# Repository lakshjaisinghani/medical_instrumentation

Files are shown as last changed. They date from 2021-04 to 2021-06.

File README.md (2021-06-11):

# Aim
The aim of this project was to build an ECG amplifier using digital signal processing in software that works synergistically with readily available hardware components. Raw ECG signals are collected, processed, and displayed in real-time using an Arduino as a microcontroller and a python script as middleware. This report provides the design decisions, calculations and results obtained.

# Real-time Heart Rate plot output
<p align="center">
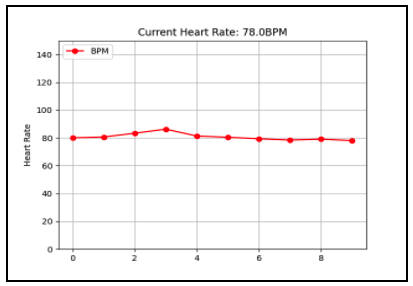
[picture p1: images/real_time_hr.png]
  
</p>

# Block Diagram
<p align="center">
  
</p>

# Components
| Component Type | Specification |
| --- | --- |
| Instrumentation Amplifier | INA114A |
| Op-Amp | LMC660 Quad Op-Amp |
| Resistors | 1x470kΩ, 3x2.2kΩ, 5x10kΩ, 1x100Ω |
| Capacitors  | 4x10μF |
| Batteries  | 2x9V |
| Microcontroller | Arduino Uno |
| ECG Electrodes  | 3 x 4mm banana to clip |
| Breadboard | 2 x mini-standard (83mmx55mm) |

# Final Circuit
## Bread board
<p align="center">
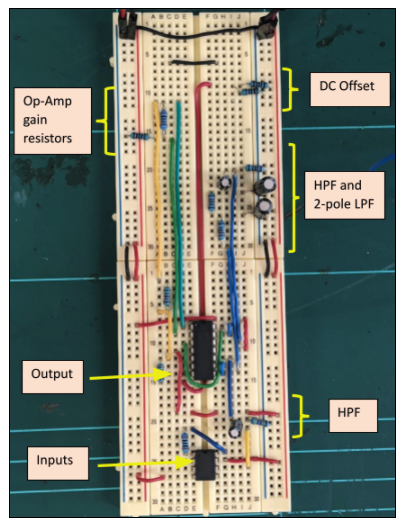
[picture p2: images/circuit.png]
  
</p>

## LTspice
<p align="center">
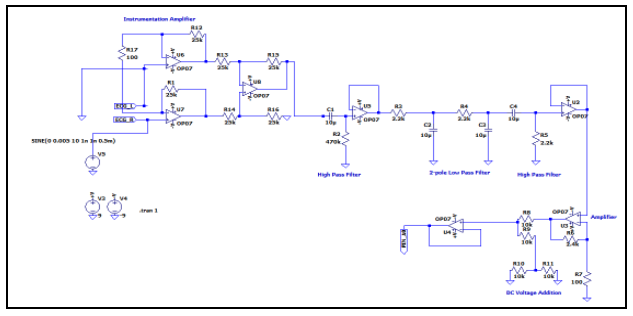
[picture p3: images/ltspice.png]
  
</p>

# Analog signal precessing results 
After each filtering stage:
<p align="center">
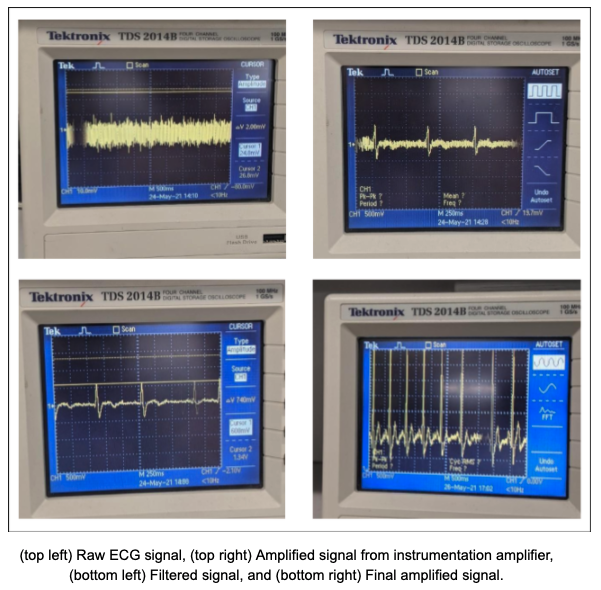
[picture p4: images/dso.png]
  
</p>

# Digital signal precessing results 
<p align="center">
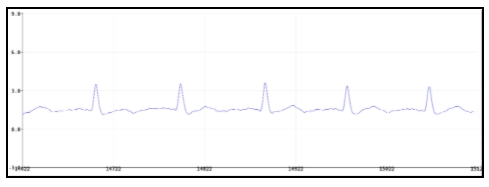
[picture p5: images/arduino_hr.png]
  
</p>

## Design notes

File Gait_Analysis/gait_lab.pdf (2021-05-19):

# ECE4081: Gait Lab

## Preliminary Questions

1. The two major calf muscles are the gastrocnemius (GA) and the soleus (SO).
2. The Gastrocnemius is responsible for plantar flexion at the ankle joint as it comprises half of the calf muscle and therefore is responsible for any fast-twitch movements (running, jumping, etc).

The soleus on the other hand, although responsible for plantar flexion at the ankle joint, mainly stabilizes the tibia limiting forward sway and hence is the most active when walking.

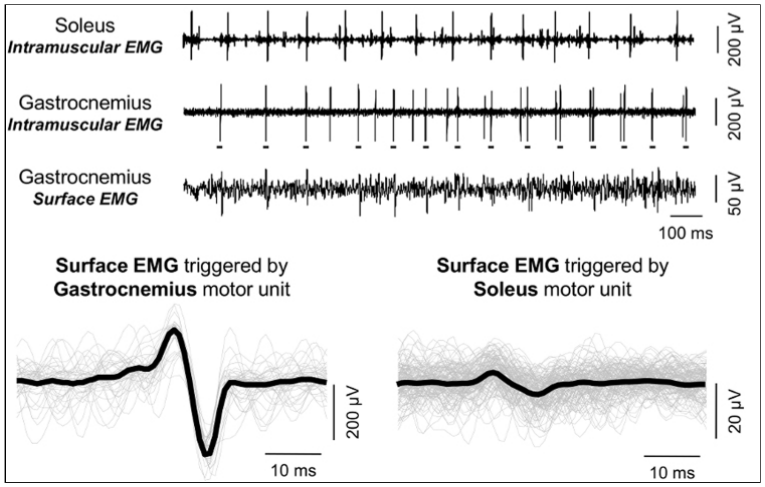
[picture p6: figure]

Fig 1. EMG from Soleus and Gastrocnemius. [1]

When looking at surface EMG data signals produced by the GA is almost 10x the magnitude of the Soleus, and intramuscularly, the SO produces more burst activity while the GA produces a single impulse [1].

3. We can place an accelerometer right above the hip, because:
a. As it is stiff, it minimizes the effects of the rotation of the body.
b. It also reduces height deviations while walking which could help us calculate the step length accurately.

4. The following is a diagram showing idiopathic toe walking, it’s a condition that involves abnormal gait due to toe strikes:

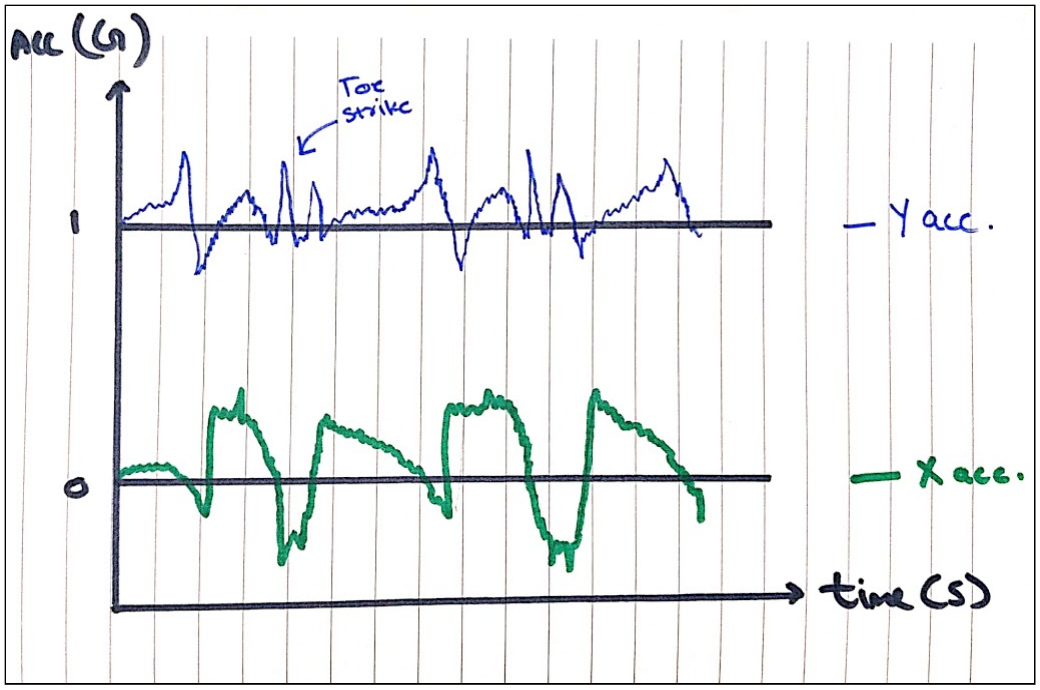
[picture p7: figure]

Fig 2. Idiopathic toe walking

## Analysing EMG Data

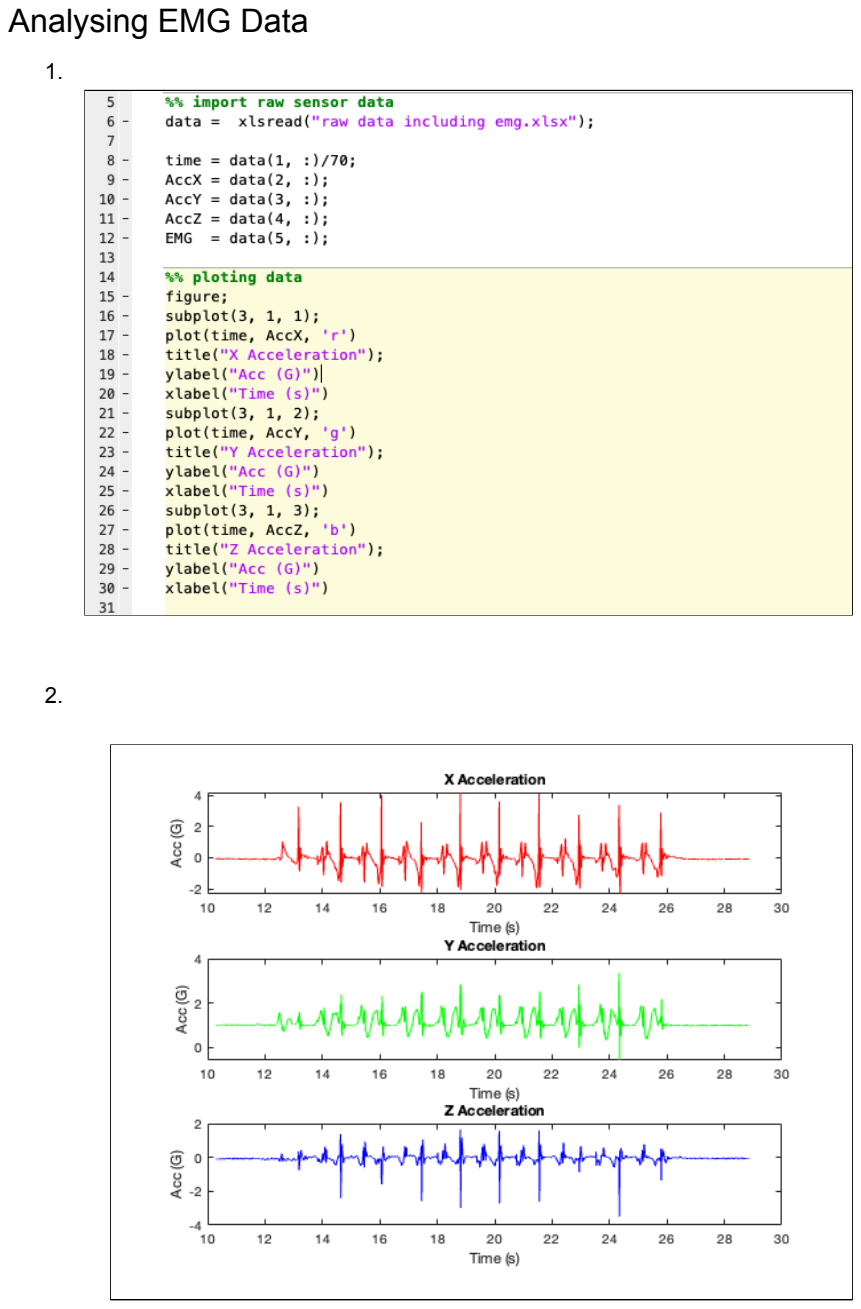
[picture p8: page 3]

1.

2.

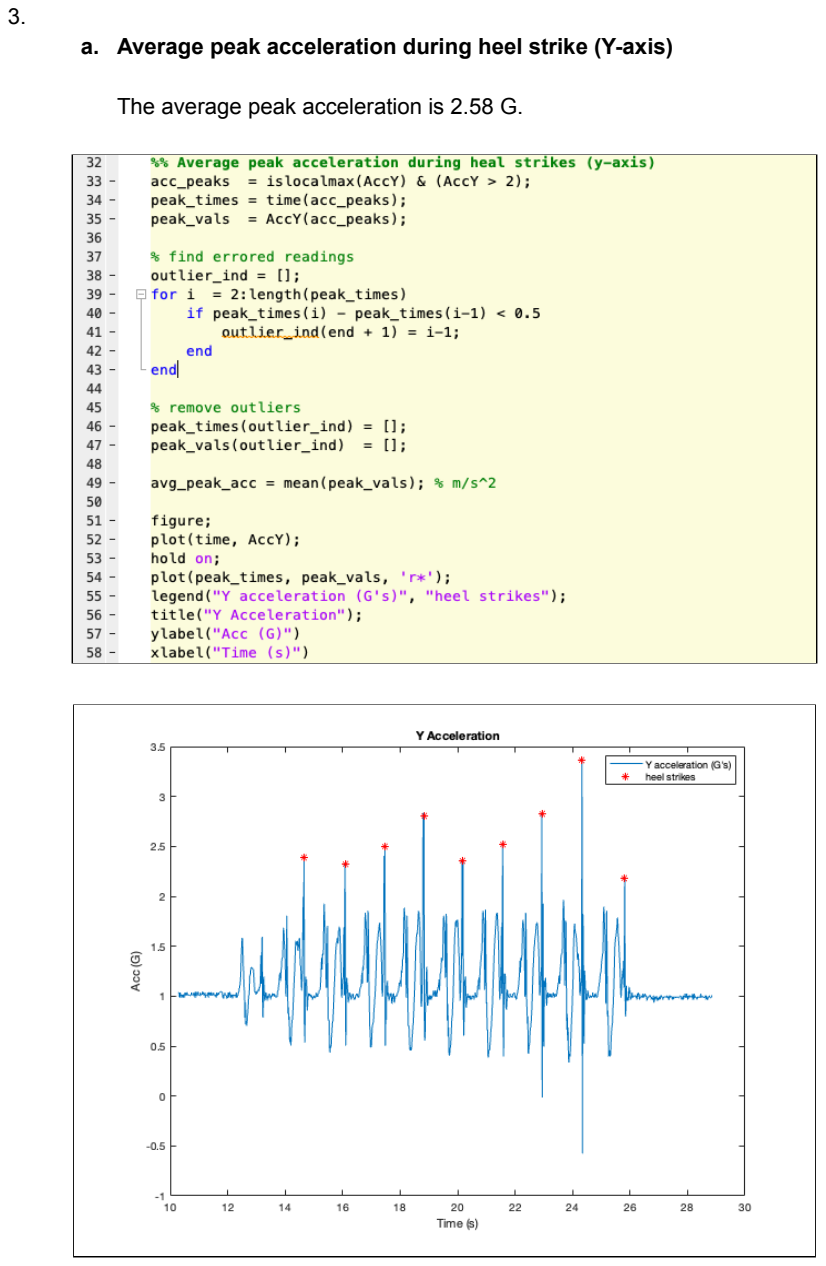
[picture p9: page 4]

3.
a. Average peak acceleration during heel strike (Y-axis)

The average peak acceleration is 2.58 G.

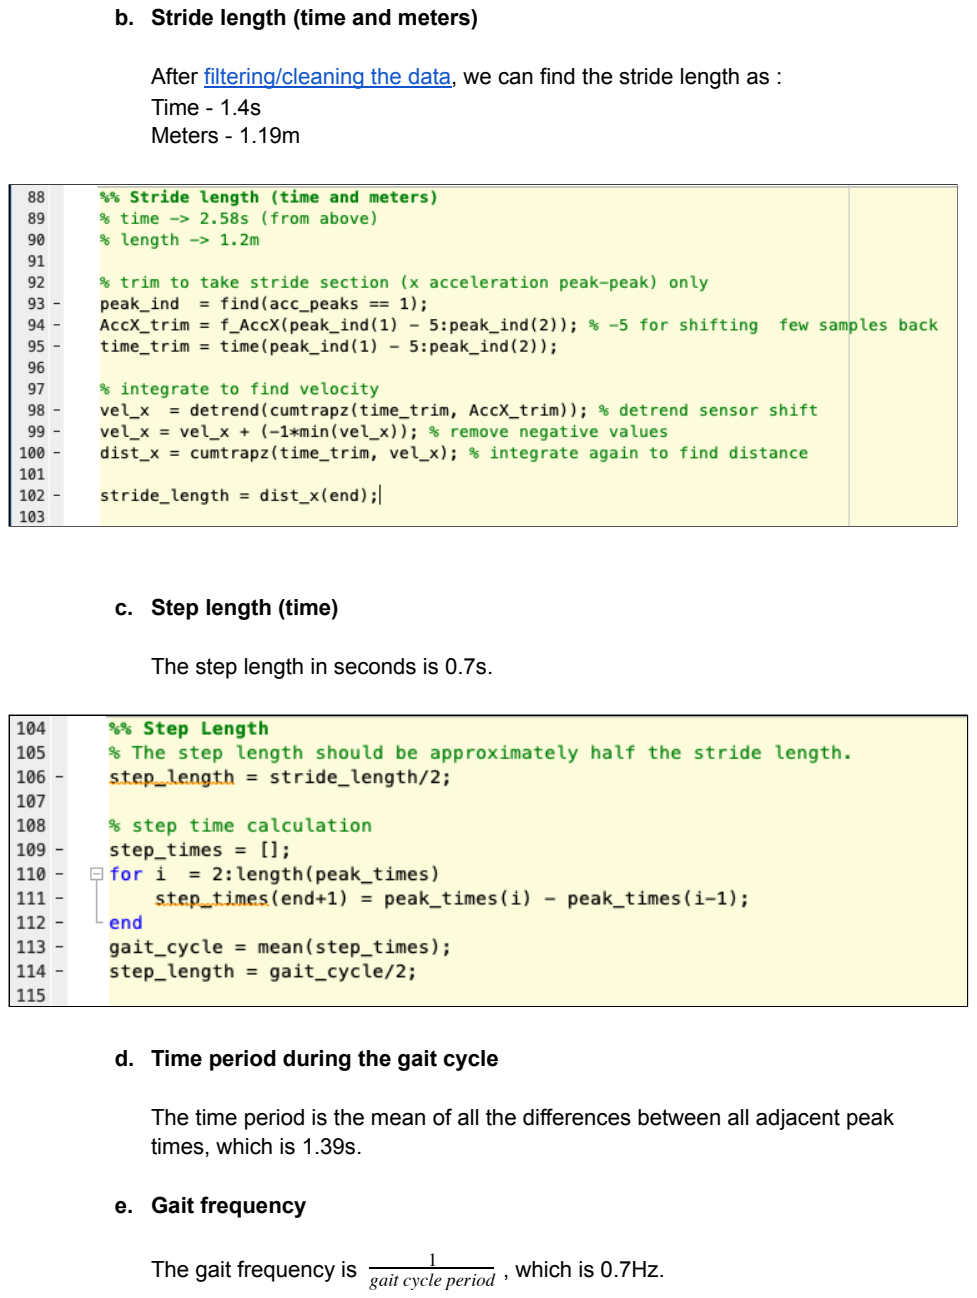
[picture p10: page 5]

b. Stride length (time and meters)

After filtering/cleaning the data, (https://github.com/lakshjaisinghani/medical_instrumentation/blob/master/Gait_Analysis/gait.m) we can find the stride length as : Time - 1.4s
Meters - 1.19m
c. Step length (time)

The step length in seconds is 0.7s.

d. Time period during the gait cycle

The time period is the mean of all the differences between all adjacent peak times, which is 1.39s.

e. Gait frequency
The gait frequency is | , which is 0.7Hz.

1
gait cycle period

## Discussion Questions

1. Surface EMG signals range from 20-200 μV [1]. Yes, amplification of the signal is required for ease of processing. Some muscles (like the biceps) may need less amplification compared to other muscles (like the muscles in our fingers) may require a higher gain [2].
2. The three sources of noise are:
a. High-Frequency Electromagnetic Radiation induced noise: This type of noise is inherent in all electronic devices, these are caused due to stray electromagnetic waves in the environment and power-line interference. We can remove such disturbances by filtering out high-frequency components (low pass filter) of the signal.
b. Low-Frequency patent artifacts: These include patient movement and other action potentials introduced into the measuring signal due to bodily functions. We can eliminate these by using a high pass filter.
c. Sensor noise: This noise is caused by the material property of the electrodes themselves, this includes Johnson–Nyquist noise (thermal noise), shot noise, and flicker noise. We can reduce such noise by using materials that produce a high signal-to-noise ratio like Ag/AgCl electrodes.

3.

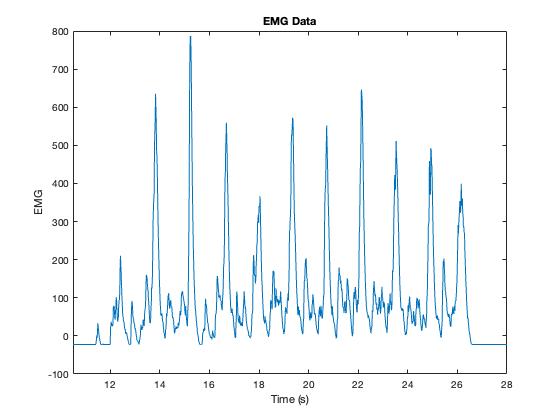
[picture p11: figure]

The EMG data provided is the calf EMG only. Therefore only two muscles, the gastrocnemius (GA) and the soleus (SO) EMG magnitude should be in the plot. These are the muscles involving forward motion.

Although not shown in the EMG, the Quadriceps femoris, the Rectus Femoris, the ILiopsoas, and the gluteus maximus are also responsible for forward motion.

4.

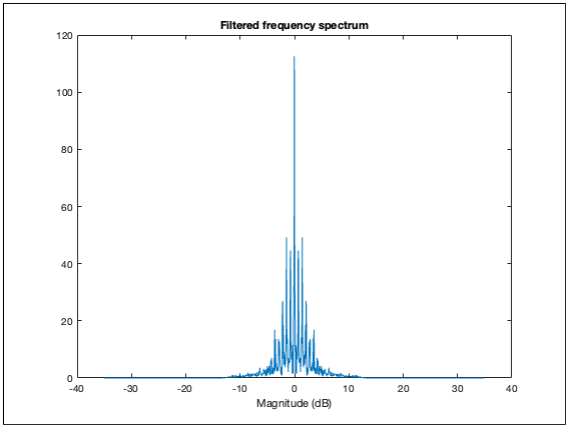
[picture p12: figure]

(Not considering the current sample frequency of 70 Hz) Looking at the frequency plot, the maximum frequency is around 10Hz, therefore we can sample from THIS SIGNAL at 20 samples/sec.

Else, we have to sample at double the Nyquist frequency, which is 140 samples/sec.

5. We can use a three-axis accelerometer in many medical health care monitoring conditions, but specifically, we can use them in fall detection and sleep monitoring.

Fall detection: We can use sudden accelerations to detect falls in either elderly or critical state patients (Parkinson’s, Alzheimer’s, etc).

Sleep monitoring: We can use movement data to measure the quality of sleep in patients. This can be a vital measurement in aiding chronic insomniacs.

6. Pressure sensors: Pressure sensors can allow medical staff to monitor the patient’s ground reactive force and calculate the weight distribution for stability study.

Accuracy: Using multiple cameras increases the accuracy of gait measurements in 3D space when compared to accelerometer-only measurements.

7. The average stride length in humans is about 0.762m. In general, | .42 | .3 Height
Step Length ≈ 0 | ± 0
[3].
8. We know that,
.42 | .3 Height
Step Length ≈ 0 | ± 0

Therefore,

0.42

1.57m

0.66 =

The Height of the individual is about 1.57m.

9. The three factors are:
a. Accuracy of the accelerometer.
b. Induced noise.
c. Sampling frequency.

Note: You can find the full code here. (https://github.com/lakshjaisinghani/medical_instrumentation/tree/master/Gait_Analysis)

## References

[1] T. Vieira, A. Botter, S. Miceli, and D. Farina, "Specificity of surface EMG recordings for gastrocnemius during upright standing", Scientific Reports, vol. 7, no. 1, 2017. Available: 10.1038/s41598-017-13369-1.
[2] M. Z. Jamal, "Signal Acquisition Using Surface EMG and Circuit Design Considerations for Robotic Prosthesis".
[3] S. Buddies, "Stepping Science: Estimating Someone's Height from Their Walk", Scientific American, 2021. [Online]. Available: https://www.scientificamerican.com/article/bring-science-home-estimating-height-walk/#:~:text=On%20av erage%2C%20adults%20have%20a,from%20about%200.41%20to%200.45). [Accessed: 16- Apr- 2021].

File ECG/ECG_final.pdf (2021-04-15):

# ECE4081: Lab 1

## Preliminary Questions

1.

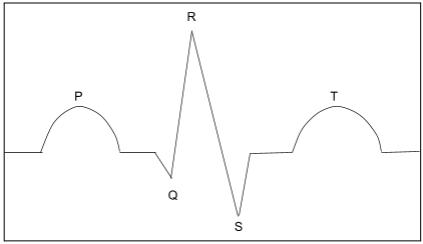
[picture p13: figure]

Fig 1: PQRST Wave

P wave - The first deflection is the P wave associated with right and left atrial depolarization. This causes atrial contraction [p-q section] (atrial fills with blood).

QRS complex - The QRS complex shows ventricular depolarisation. It is the electrical activity that first runs through the AV node, then through the interventricular septum, and finally through the ventricle walls.

T Wave - Shows ventricular repolarization. Before this, the s-t segment denotes ventricular contraction, i.e. blood flows out of ventricles.

2.

The three lead system is used to measure the differences between electrical potentials at different sites of the body on the frontal plane. The leads used are bipolar and are placed on the right arm, left arm and left leg (forming the einthoven's triangle).

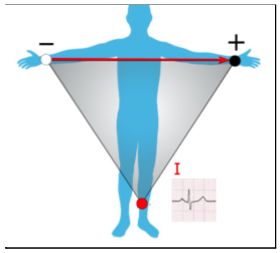
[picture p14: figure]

Fig 2. Einthoven's triangle [1]

It can be seen from the image below that each channel reads a slightly different PQRST complexes.That is, depending on the voltage read between two of the electrodes, the depolarisation and repolarisation electric vectors are seen from different views (some specific artifacts of the complex are more amplified from a certain view). Therefore looking at the same signal from different views gives us a better overall understanding of the complex.

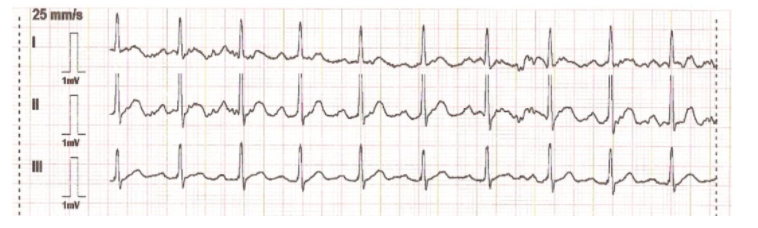
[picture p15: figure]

Fig 3. 3-Lead ECG from different reference points [2]

a) We use the direction of electrical flow across the cardiac tissue, referenced to the apex (Right to Left, lead 1) to get a clearer upright QRS complex (Specifically the P wave). This is because the direction of depolarization (electric vector) heads towards the positive electrode, which leads to the largest deviation in voltage magnitude [3, 4].
b) To view an electrical signal, we need to zero reference it to some known voltage to measure a potential difference.

3.

An RCD, or residual current device, is a life-saving device which is designed to prevent you from getting a fatal electric shock.

RCDs operate by measuring the current balance between two conductors using a differential current transformer. This measures the difference between current flowing through the live conductor and that returning through the neutral conductor.

Therefore, if there is a faulty medical device, which is not grounded correctly, that comes in contact with a lower resistance path to ground (victim of electrocution), it can trip the power supplied to the room which can reduce risks significantly.

## Data Collection and Recording

### ECG

### 1. Take a screenshot and identify the PQRST waveforms. What would happen if the

two electrode leads were swapped?

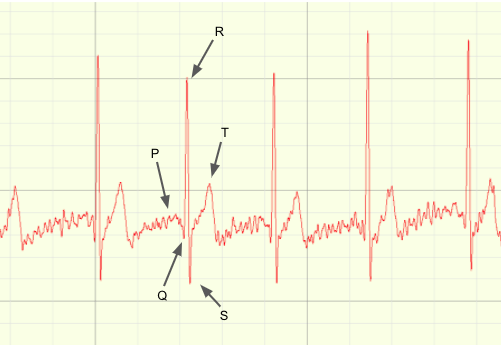
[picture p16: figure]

Fig 4. ECG sample

If the electrodes are swapped, the signal would be flipped, as shown in figure 5.

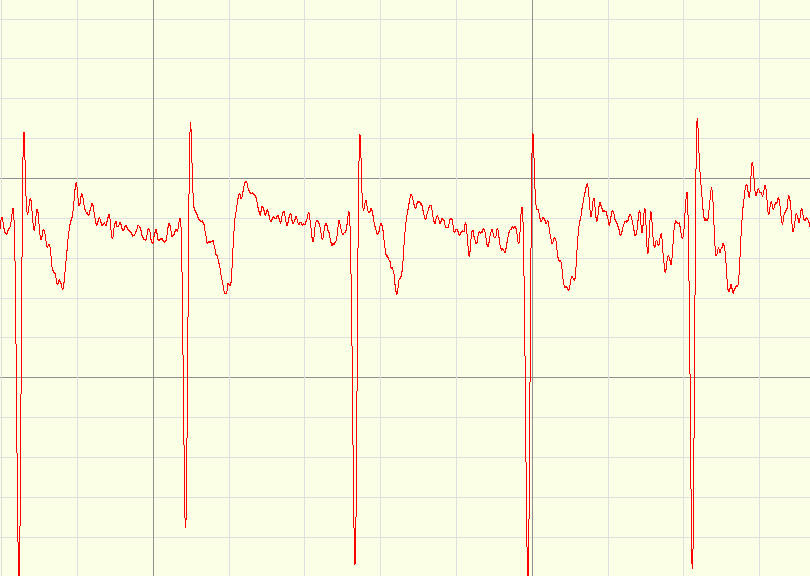
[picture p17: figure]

Fig 5. Flipped ECG signal sample

### 2. Turn off the 35-Hz LPN filter and take another recording. Observe what happens to

the signal. Explain why.

Turning off the 35-Hz low pass filter allows all the 50-Hz noise generated by the power source to appear at the signal. In the case of this lab we used an isolation transformer as the pseudo power source.

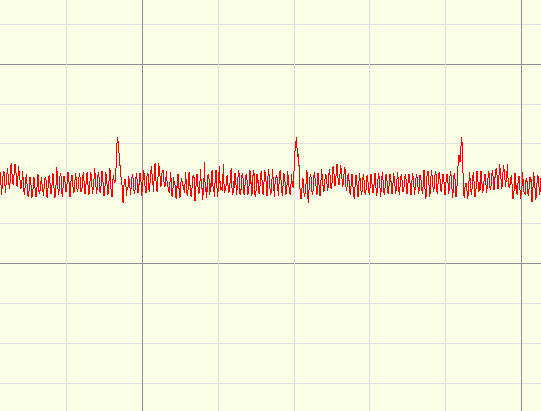
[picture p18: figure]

Fig 6. 35-Hz LPF turned off

### 3. Turn the 35-Hz LPN filter back on. Now turn off the HP filter and take another

recording. Observe what happens to the signal. Why?

The HP filter removes the slow oscillation frequencies introduced into the signal due to respiration. So, Turning it off introduces a low frequency component that causes the whole ECG signal to slow oscillations.

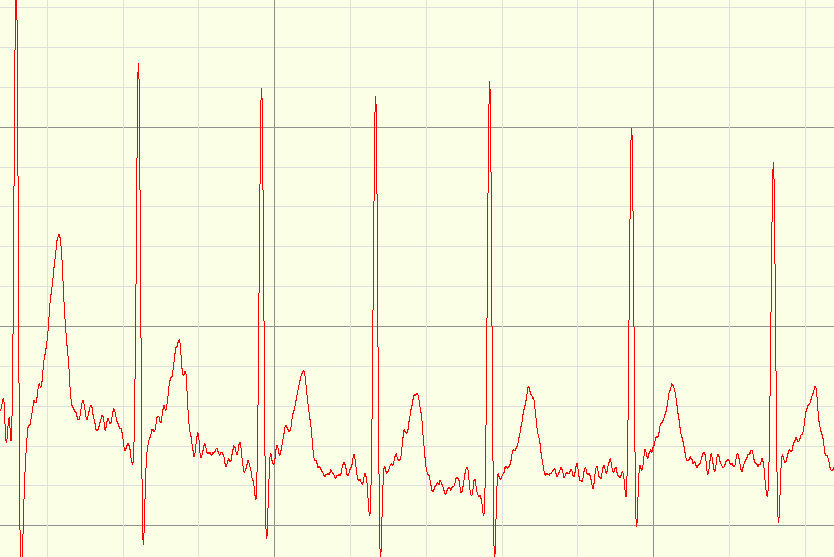
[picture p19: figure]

Fig 7. HP filter turned off

### 4. Disconnect the shield to one of the shielded electrodes. What happens?

Disconnecting the shield on one of the electrodes introduces the surrounding electromagnetic interference into the ECG signal.

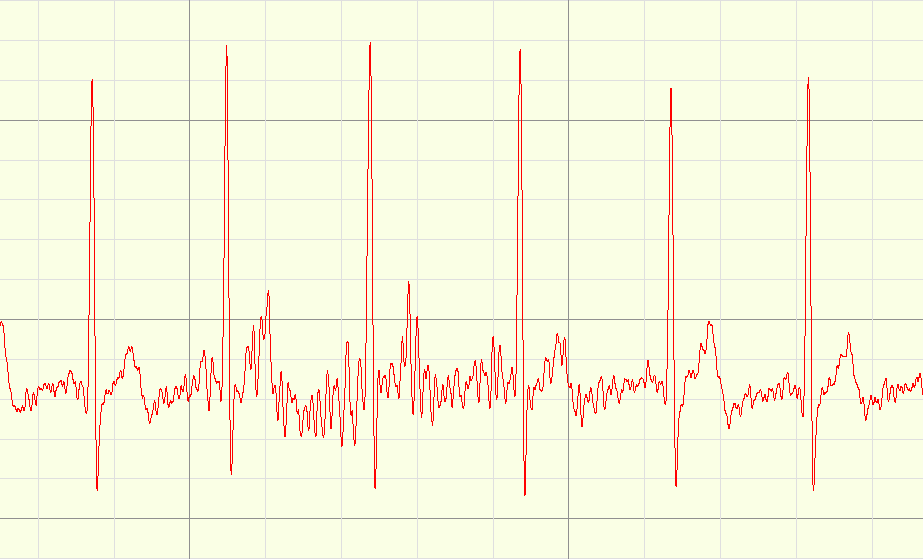
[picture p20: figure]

Fig 8. One shield disconnected

### 5. Disconnect the shield to the other electrode so that both shields are now

disconnected. What happens?

Disconnecting both shields ignores most of the EM interference. Probably due to the differential instrumentation amplifier in the monitors circuitry that rejects the common EM disturbance.

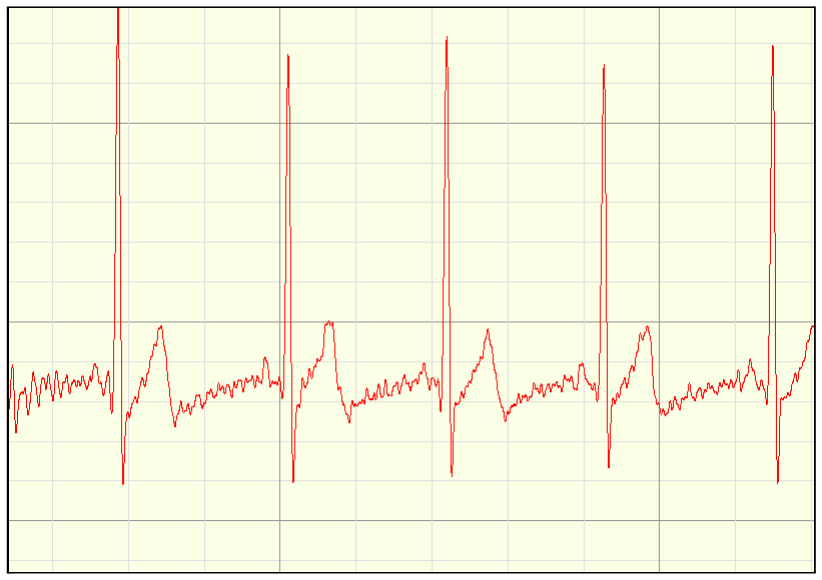
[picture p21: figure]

Fig 9. Both shields disconnected

### 6. Remove the gel from the electrode surfaces and take another recording. What

happens?

Removing the gel from the electrode surfaces didn’t cause much change when stationary. But, slight movements caused erroneous readings due to the conducting path between the skin and electrode not being consistent.

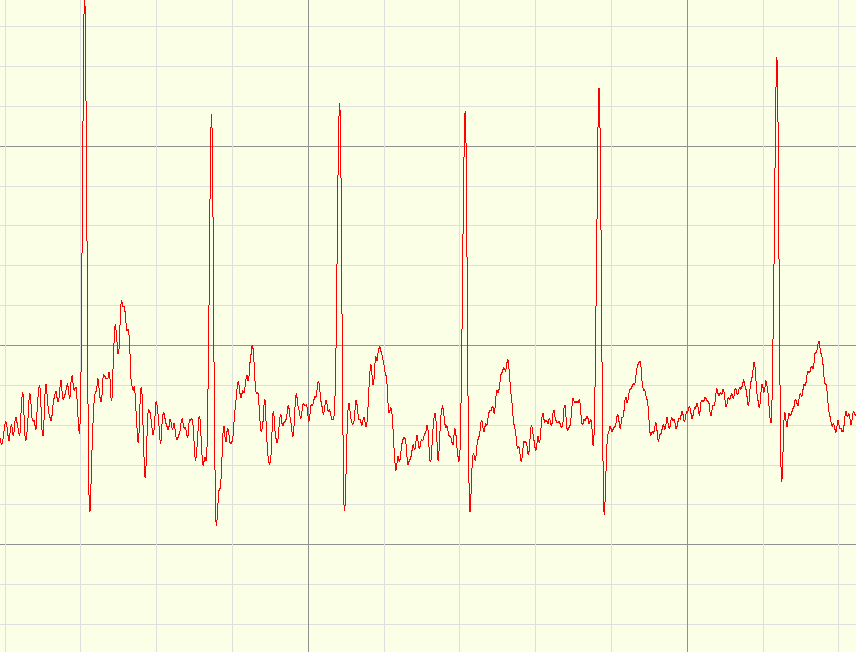
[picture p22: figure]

Fig 10. Removed gel from electrode surface

### 7. Use the Data Acquisition button to collect both ECG and R-R interval data for a 5

minute time interval. Is this what you would expect to see and why?

The R-R interval is the time difference between two R peaks in an ECG PQRST complex. The reading provided is what we expected, this is because it was constant for the most part, but as the heart rate increased the R-R interval decreased and vice-versa.

### SpO2

### 1. Observe the SpO2 waveform. How does it compare to the ECG waveform? What

are the differences? Why is it different?

The SpO2 waveform measures the concentration of oxygen under the tissue being measured. This concentration of oxygen is related to the amount of hemoglobin in the blood (oxygenated blood) being pumped by the heart to that tissue. Therefore, this signal has nothing to do with the electric vectors measured during an ECG.

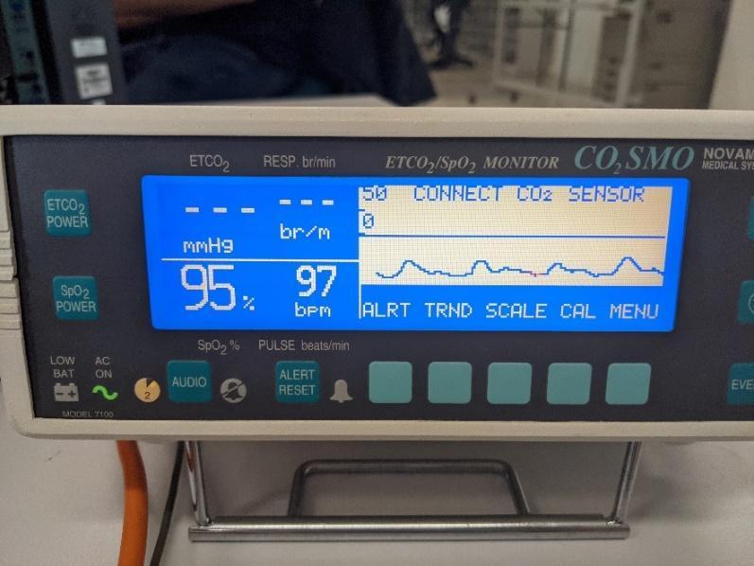
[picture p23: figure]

Fig 11. SpO2 waveform.

This distinction makes it clear that there would be no PQRST complex in an SpO2 waveform, but just the amount of oxygen over time. Hence, the signal is a lot smoother and has distinct peaks.

### 2. Manually calculate the interval between the peaks of SpO2 waveform. What can

you do to make this measurement more accurate?

In figure 3, there are almost 4 peaks in the 3 second interval. Therefore, there are 1.33 peaks per second. Which calculates to about 80 bpm.

## Discussion Questions

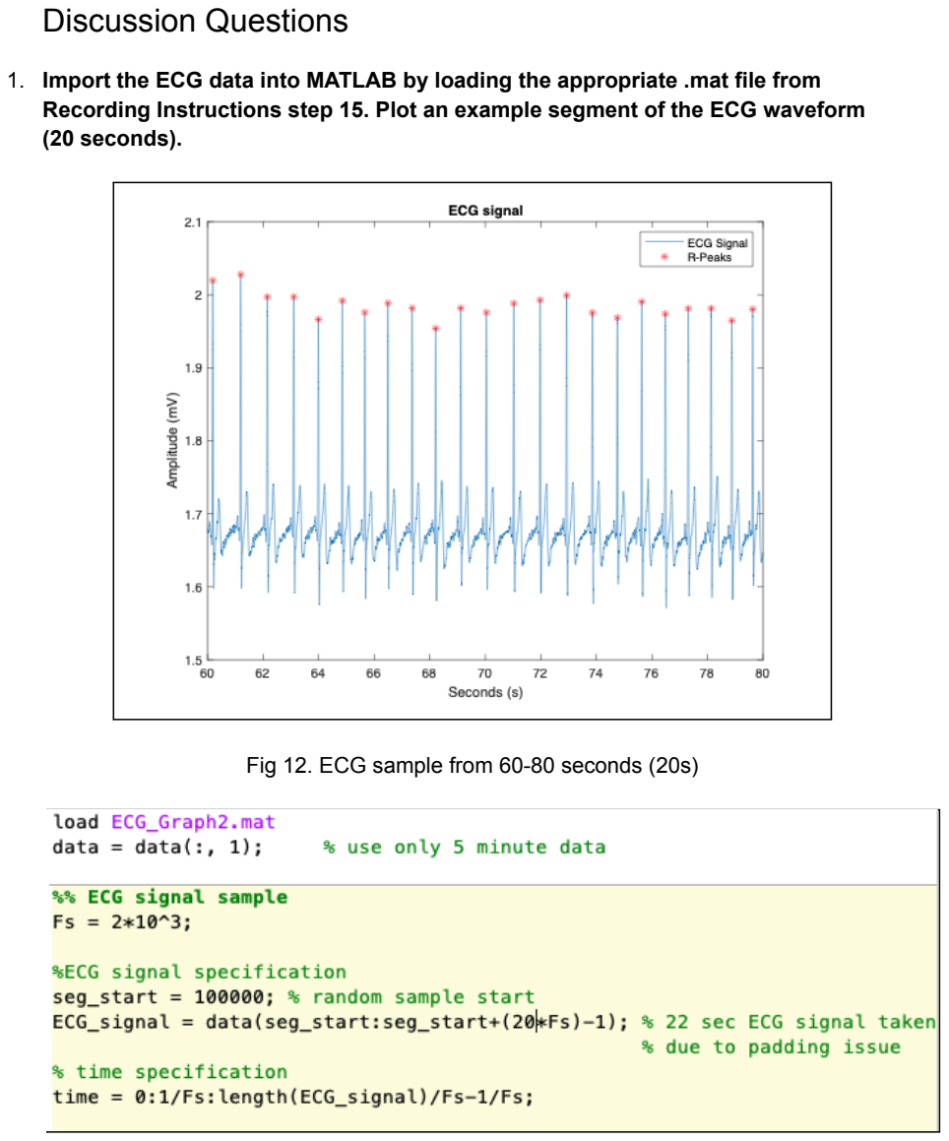
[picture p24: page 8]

1. Import the ECG data into MATLAB by loading the appropriate .mat file from Recording Instructions step 15. Plot an example segment of the ECG waveform (20 seconds).

Fig 12. ECG sample from 60-80 seconds (20s)

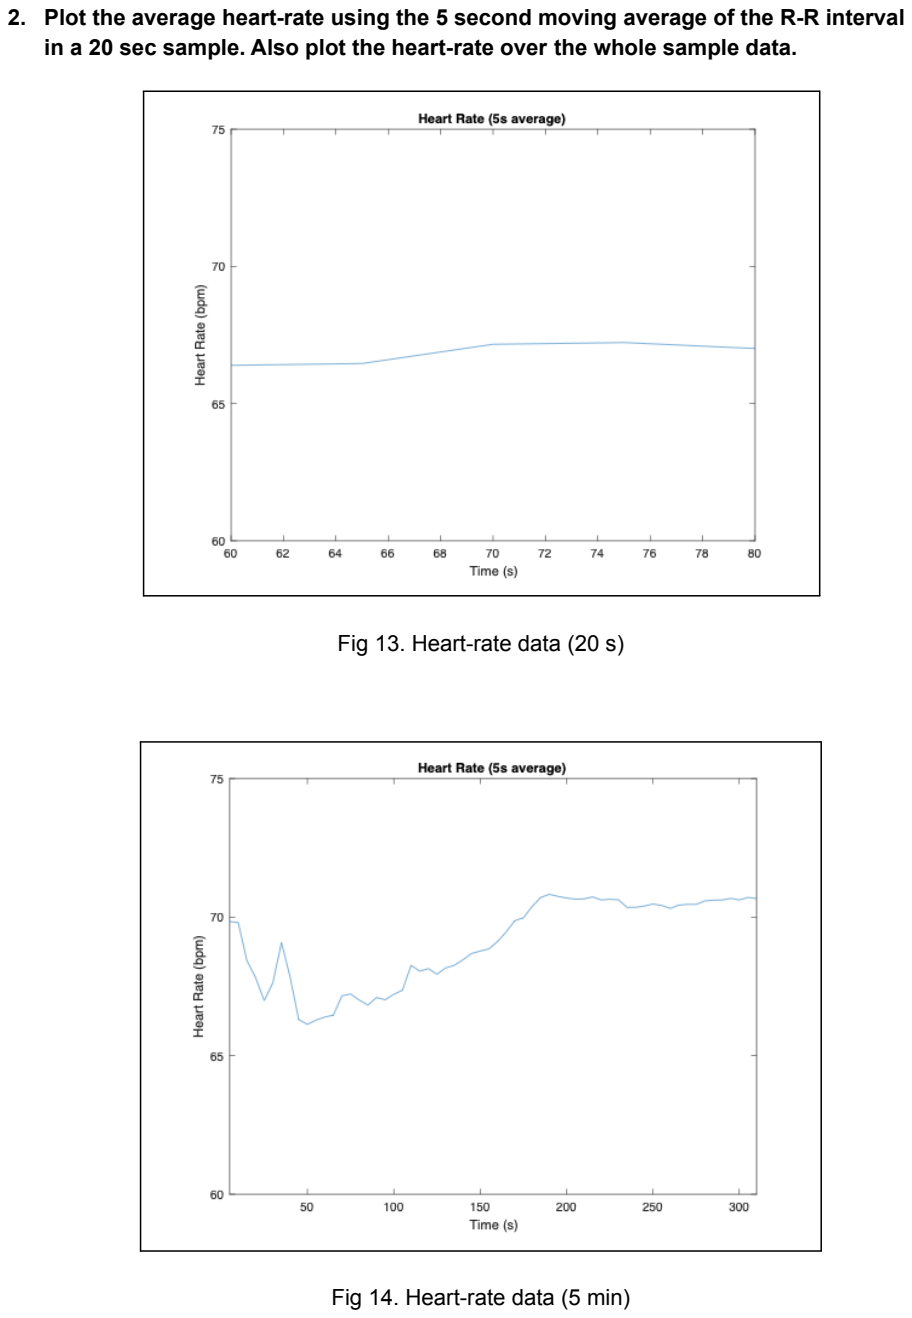
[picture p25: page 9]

### 2. Plot the average heart-rate using the 5 second moving average of the R-R interval

in a 20 sec sample. Also plot the heart-rate over the whole sample data.

Fig 13. Heart-rate data (20 s)

Fig 14. Heart-rate data (5 min)

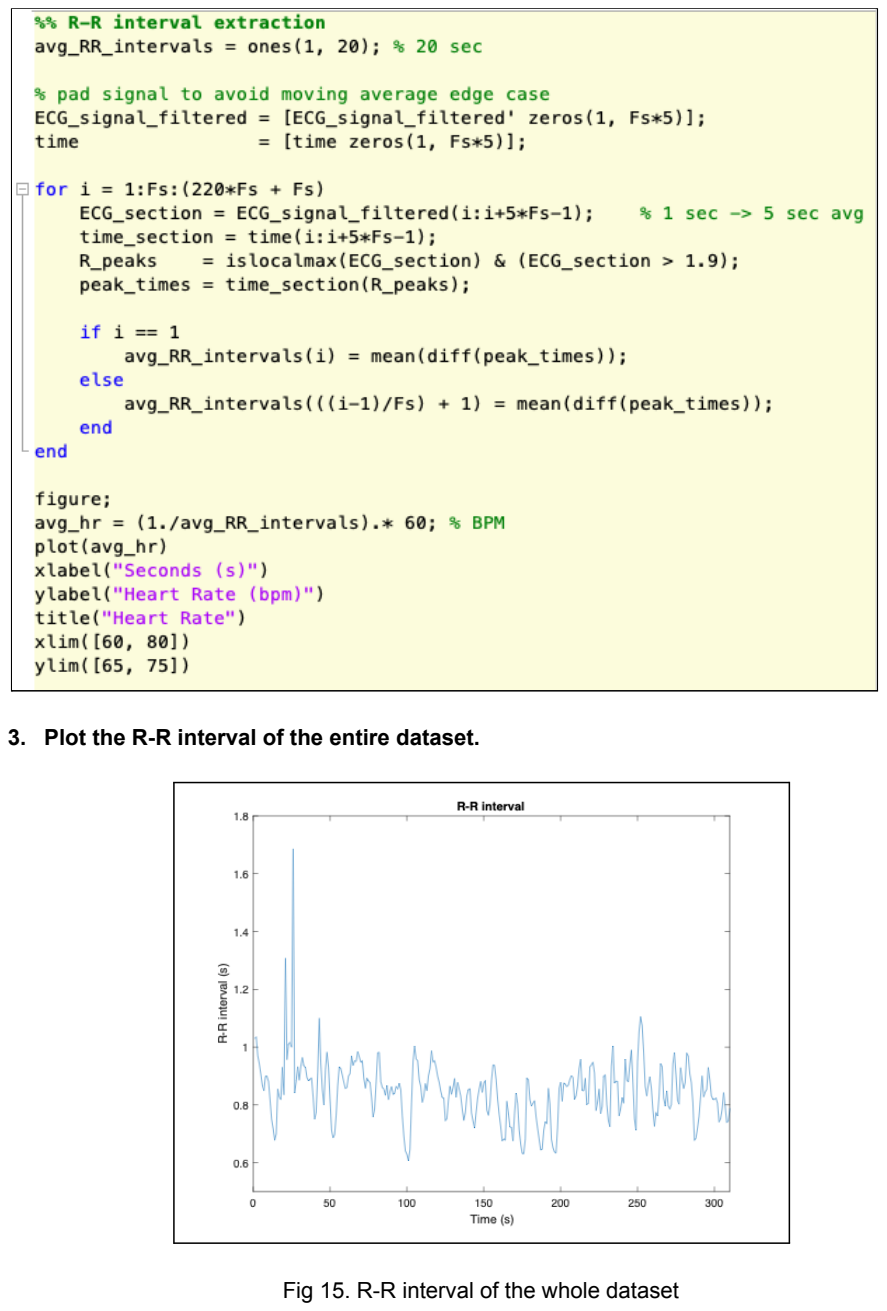
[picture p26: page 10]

3. Plot the R-R interval of the entire dataset.

Fig 15. R-R interval of the whole dataset

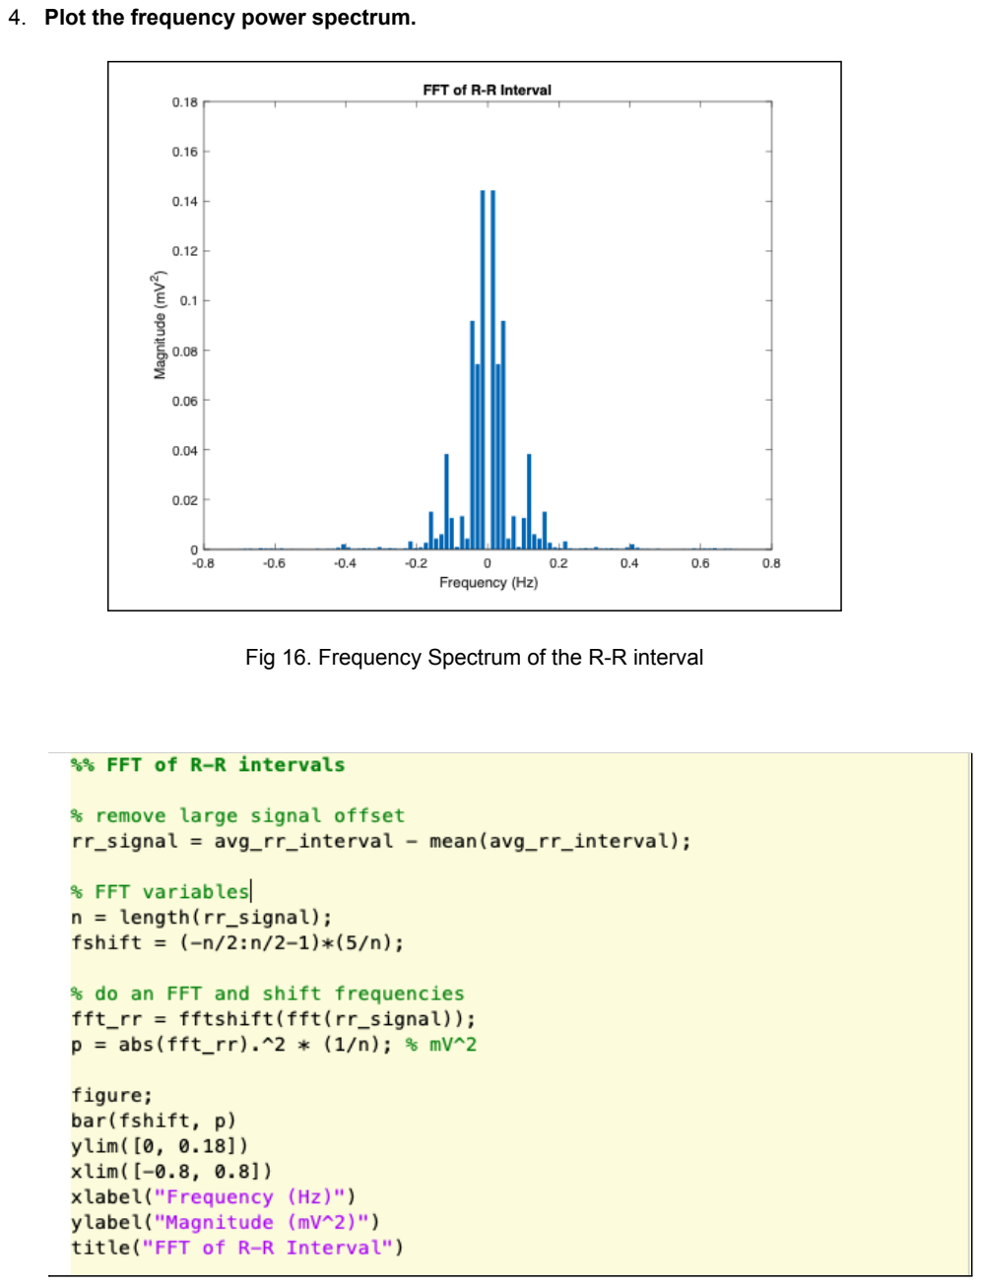
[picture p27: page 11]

4. Plot the frequency power spectrum.

Fig 16. Frequency Spectrum of the R-R interval

### 5. Is there any interference from the mains in the frequency plot? Describe what

typical interference looks like.

There is no mains interference in the frequency plot as this is not the ECG frequency spectrum, but the DTFT of the R-R intervals. Also, even if the ECG’s DTFT was plotted, we won’t see any mains interference as we used an analog 35-Hz low pass filter when collecting the data.

6. List three sources of noise that interfere with ECG recording.

The three sources of noise are:

(a) 50 Hz mains interference
(b) High frequency electromagnetic interference.
(c) Action potentials generated for respiration.

### 7. What would happen if you used a simple ECG lead with only 2 electrodes to

record? Where would you place those electrodes?

If there are only two electrodes, we’ll place them on either wrist. The only difference would be the wrong normalized voltage readings as we don’t have a reference, which is fine if we only care about the heart rate (peaks).

### 8. Plot the R-R interval spectrum and find the peak frequency in the below bands of

R-R interval spectrum.

The frequency power spectrum is plotted in figure 6 above.

Measurement | Frequency at which max occurs
Very Low Frequency (0 to 0.04Hz) | 0.01Hz
Low-Frequency (0.04 to 0.15Hz) | 0.11 Hz
High-Frequency (0.15 TO 0.4Hz) | 0.159 Hz

9. Repeat from step 12 for a second subject.
Measurement | Frequency at which max occurs
Very Low Frequency (0 to 0.04Hz) | 0.013Hz
Low-Frequency (0.04 to 0.15Hz) | 0.2 Hz
High-Frequency (0.15 TO 0.4Hz) | 0.13 Hz

### 10. Spectral analysis of heart rate variability can be a useful tool for diagnosing

different heart conditions. What physiological events do the peaks in the different frequency bands reflect?

Very Low - Indicates use of the renin-angiotensin system [6, 8]

Low Frequency - indicates anxiety and panic, and/or coronary heart disease [8]

High Frequency - indicates resilience from stress. [7]

### 11. List three factors that may account for any variation between subjects?

The following factors may account for variation between subjects:

(a) Physical attributes (height, weight, etc)
(b) Exercise prior to measurement
(c) Caffeine and/or smoking prior

### 12. What would the ECG look like for various irregular heartbeat conditions such as

arrhythmia? Describe two.

There are two kinds of arrhythmia, Bradycardia and Tachycardia. In bradycardia, The heart rate is slow (under 60 bpm). It can indicate a heart abnormality like heart block and sick sinus syndrome. On the other hand, when someone has tachycardia, the heart rate is fast (over 100 bpm). These show Atrial fibrillation, frill, and Wolff-Parkinson-White syndrome. [5]

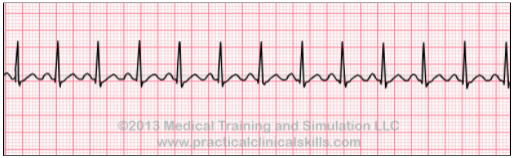
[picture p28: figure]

Fig 17: Tachycardia [5]

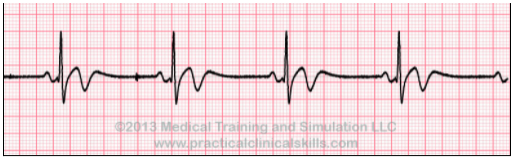
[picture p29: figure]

Fig 17: Bradycardia [5]

### 13. Describe the difference between how ECG and a SpO2 monitor measure heart

rate. Focus on the sensors and physiological measurements that are being made.

An SpO2 monitor uses pulse oximetry to measure blood oxygen saturation with the use of a photo optic sensors placed on the fingertips of the patient. More specifically, this sensor measures the percentage of hemoglobin in the blood being pumped to that tissue over time (see figure 11).

An ECG on the other hand uses electrodes placed on the body to measure the depolarisation and repolarisation of the heart, due to action potentials, as a voltage. Therefore, SpO2 monitor measures heart rate using the time intervals between the peak times of when there is maximum oxygen in the tissue, and an ECG monitor measures heart rate using the time intervals between the peak times of the electric vectors (PQRST waves).

### 14. Describe a situation in which you might elect to use an SpO2 monitor to measure

heart-rate.

In a commercial situation (eg: a wearable fitness device) when ease of use and cost are the parameters of interest, using a SpO2 sensor is preferred.

In a medical situation, it might be easier to use an SpO2 monitor when it’s an operation/surgical scenario or when quick and easy readings are required.

15. List two advantages of SpO2 over ECG. List two disadvantages.

Advantages of SpO2 over ECG:

(a) Cost: SpO2 monitors are usually cheaper than ECG monitors.
(b) Safety from electrocution: As we are using pulse optometry (no electrical path through the body) and not electricity to measure HR as done in ECG.

Disadvantages of SpO2 over ECG:

(a) Accuracy: ECG monitors are highly accurate, whereas SpO2 monitors just estimate HR using tissue hemoglobin concentration.
(b) Heart condition detection: We can’t use an SpO2 monitor to diagnose heart conditions like arrhythmia and fibrillation precisely.

Note: click here for full code (https://github.com/lakshjaisinghani/medical_instrumentation/tree/master/ECG)

## References

[1] Y. Wong, Sensors_basics. .
[2]"Lead systems – how an ECG works | CardioSecur", Cardiosecur.com, 2021. [Online]. Available:
https://www.cardiosecur.com/magazine/specialist-articles-on-the-heart/lead-systems-how-an-ecg-works. [Accessed: 26- Mar- 2021].

[3]S. Meek, "ABC of clinical electrocardiography: Introduction. I---Leads, rate, rhythm, and cardiac axis", BMJ, vol. 324, no. 7334, pp. 415-418, 2002. Available: 10.1136/bmj.324.7334.415.

[4] mefanet.lfp.cuni.cz › download (https://mefanet.lfp.cuni.cz/download.php?fid=104)
[5]"Arrhythmia | Definition | Practice Drills", Practical Clinical Skills, 2021. [Online]. Available:
https://www.practicalclinicalskills.com/arrhythmia. [Accessed: 26- Mar- 2021].

[6]E. Miranda Dantas et al., "Spectral analysis of heart rate variability with the autoregressive method: What model order to choose?", Computers in Biology and Medicine, vol. 42, no. 2, pp. 164-170, 2012. Available: 10.1016/j.compbiomed.2011.11.004.

[7]"Heart Rate Variability vs. Heart Rate - Elite HRV", Elite HRV, 2021. [Online]. Available: https://elitehrv.com/heart-rate-variability-vs-heart-rate. [Accessed: 26- Mar- 2021].

[8] Alexander Gersten, Ori Gersten, Adi Ronen and Yair Cassuto (March 23rd 2019). The RR Interval Spectrum, the ECG Signal, and Aliasing, Fourier Transforms - Century of Digitalization and Increasing
Expectations, | Goran | S. | Nikoli? | and | Dragana | Z. | Markovi?-Nikoli?, IntechOpen, DOI:
10.5772/intechopen.85327. | Available | from:
https://www.intechopen.com/books/fourier-transforms-century-of-digitalization-and-increasing-expectations/the-rr-interval-spectrum-the-ecg-signal-and-aliasing (https://www.intechopen.com/books/fourier-transforms-century-of-digitalization-and-increasing-expectations/the-rr-interval-spectrum-the-ecg-signal-and-aliasing)

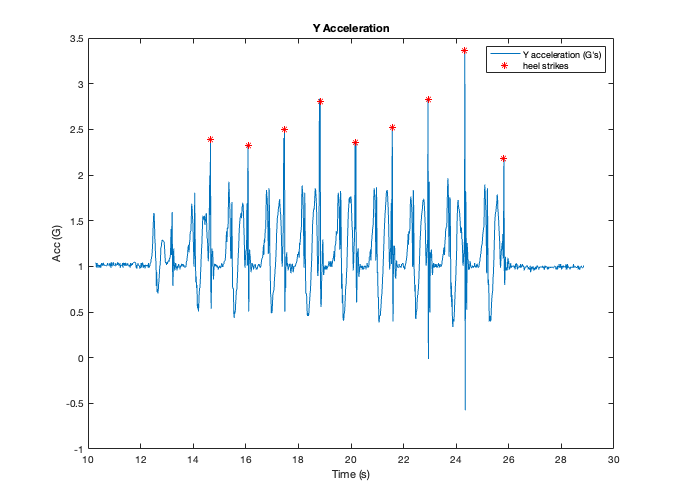
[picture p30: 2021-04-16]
Gait_Analysis/images/y_peak.png

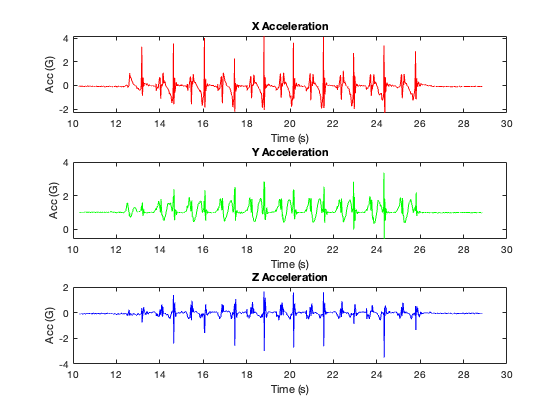
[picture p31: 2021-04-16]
Gait_Analysis/images/data.png

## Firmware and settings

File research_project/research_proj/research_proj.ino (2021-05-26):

#include "digcomp.h"

// arduino def
int analogPin = A0; 

// read variables
int val = 0; 
float voltage = 0.0;
float ECG_V   = 0.0;
int moving_avg = 100;

// filtering
float lp_out_sig;
float b_lp[2] = {0, 0.4665};
float a_lp[2] = {1, -0.5335};
float lp_in[2];
float lp_out[2];

float hp_out_sig;
float b_hp[2] = {0, -1.0000};
float a_hp[2] = {1, -0.0592};
float hp_in[2];
float hp_out[2];

dig_comp lpfil(b_lp, a_lp, lp_in, lp_out, 2, 2);
dig_comp hpfil(b_hp, a_hp, hp_in, hp_out, 2, 2);

// find maxima
float prev_val = 0.0;
float curr_val = 0.0;
float next_val = 0.0; 

void setup() {
  Serial.begin(9600);           //  setup serial
}

void loop() {
  val = analogRead(analogPin);  // read the input pin

  for (int i = 0; i < moving_avg; i++)
  {
    voltage += val * (5.0 / 1023.0);
  }

  ECG_V = voltage/moving_avg;

  lp_out_sig = lpfil.calc_out(ECG_V);
  
  Serial.println(lp_out_sig); 
 
  voltage = 0.0;
}

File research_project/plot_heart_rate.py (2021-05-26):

import serial
import numpy as np
import matplotlib.pyplot as plt
from drawnow import *
import time
import re
import csv
import scipy.signal as signal
plt.ion()

thresh = 10    

ECG_data = []
HR_data  = []
HR_print = []
arduinoData = serial.Serial('/dev/ttyACM0', 9600)

cnt = 0
cnt_hr_1 = 0
cnt_hr_2 = 0

curr_peak = 0
prev_peak = 0

start_time = 0
end_time   = 0
switch     = 0

def makeFig():
    plt.ylim(0,150)                               
    plt.title('Current Heart Rate: ' + str(round(HR_print[-1])) + 'BPM')     
    plt.grid(True)                                 
    plt.ylabel('Heart Rate')                            
    plt.plot(HR_print, 'ro-', label='BPM')      
    plt.legend(loc='upper left')                    

with open("ecg.csv", 'w', newline='') as file :
    writer = csv.writer(file)
    writer.writerow(['Time', 'ECG'])

while True:
    while (arduinoData.inWaiting()==0): 
        pass 
    
    try:
        arduinoString = str(arduinoData.readline())
        
        ECG = float(arduinoString[2:6])
        ECG = ECG * ECG

        if ECG:
            ECG_data.append(ECG)

            with open("ecg.csv", 'a', newline='') as file :
                writer = csv.writer(file)
                writer.writerow([time.time(), ECG])

        peaks, _ = signal.find_peaks(np.array(ECG_data), distance=10)

        
        if ECG_data[peaks[0]] > thresh:
            curr_peak = ECG_data[peaks[0]]

        HR = 0
        if curr_peak != prev_peak and switch:
            start_time = time.time()
            switch = 0 
            prev_peak = curr_peak

        if curr_peak != prev_peak and not switch:
            HR = (1/(time.time() - start_time)) * 60
            switch = 1 
            prev_peak = curr_peak

        if HR > 30 and HR < 200:
            HR_data.append(HR)


            cnt_hr_1 += 1
            if cnt_hr_1 > 7:
                HR_data.pop(0)
            
            mean_hr = np.mean(np.array(HR_data))
            HR_print.append(mean_hr)

            cnt_hr_2 += 1
            if cnt_hr_2 > 10:
                HR_print.pop(0)

            if len(HR_print) > 1:
                drawnow(makeFig)
                plt.pause(.000001) 

        cnt += 1
        if cnt > 50:
            ECG_data.pop(0)
            
    except:
        pass

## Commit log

2021-03-24 Added ECG lab
    [ECG_Lab.gtl]
2021-05-19 feature: added filtering matlab code
2021-05-19 feat arduino code
2021-05-22 added real time plotiing, doesn't work great tho
    [plot_heart_rate.py, research_proj.ino]
2021-05-23 fix: HR plotting fixed by upscaling peaks /
    [plot_heart_rate.py]
2021-05-26 final demo
    [ecg.csv]
2021-06-02 fix: directory structure changed
    [ecg.csv]
